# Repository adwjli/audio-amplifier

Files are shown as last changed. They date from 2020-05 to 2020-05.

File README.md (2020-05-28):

# Audio Amplifier

## Introduction
This is a Class D audio amplifier built around a TPA3122D2N amplifier from Texas Instrument. It features two stereo audio jacks that allows two sources to be connected to the amplifier at the same time (for example a music player and a laptop).

A slide switch allows selection of switch input source to feed into the amplifier. The onboard potentiometer provides volume control. Power is provided using a 16V DC 2A adapter. This audio amplifier was designed as part of a custom audio-visual setup.

The amplifier accepts an input voltage between 15V to 25V. The output power is 10W per channel. It can drive speakers with impedances between 4 and 8 Ohms.

## Gallery

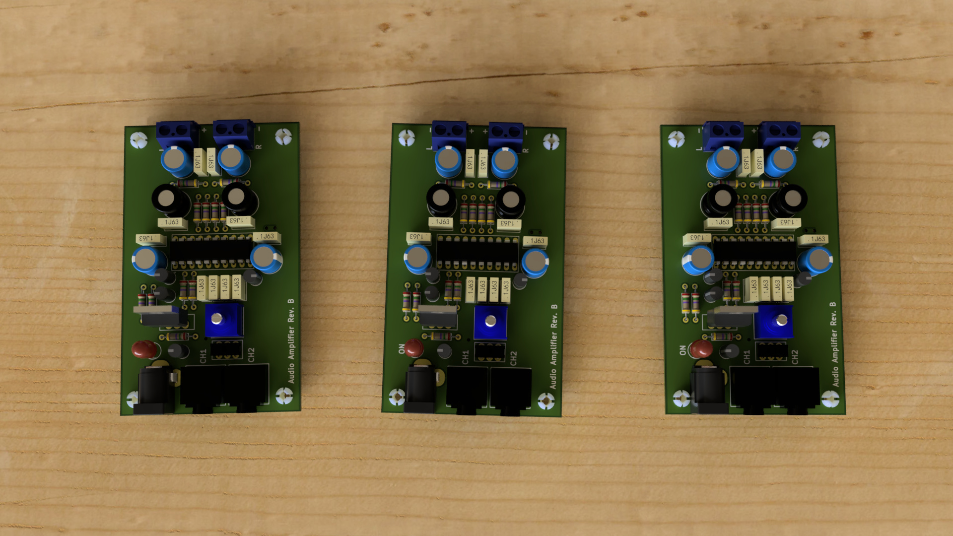
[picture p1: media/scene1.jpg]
Audio Ampifier PCBs, assembled.


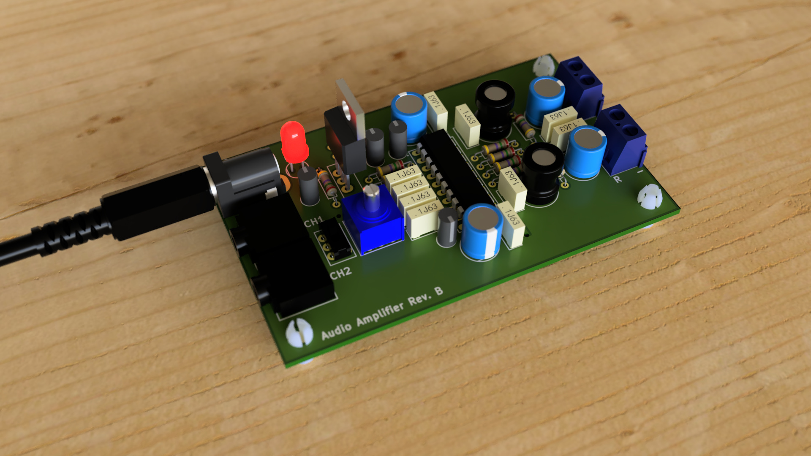
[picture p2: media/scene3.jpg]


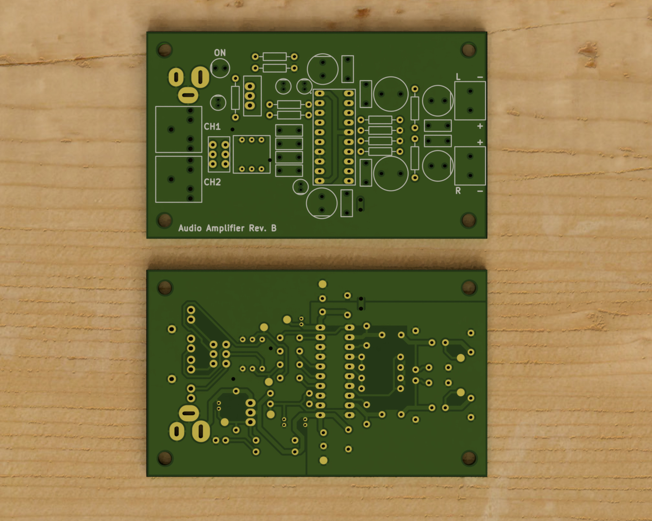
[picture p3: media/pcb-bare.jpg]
Audio Amplifier PCB bare.


## Copper Layers

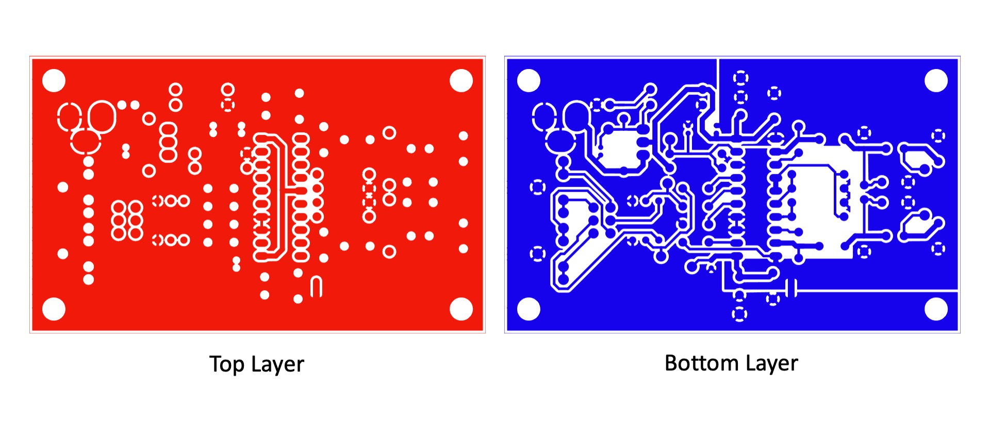
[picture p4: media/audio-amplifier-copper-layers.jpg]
Audio Amplifier powered.


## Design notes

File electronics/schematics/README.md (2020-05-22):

# Schematics

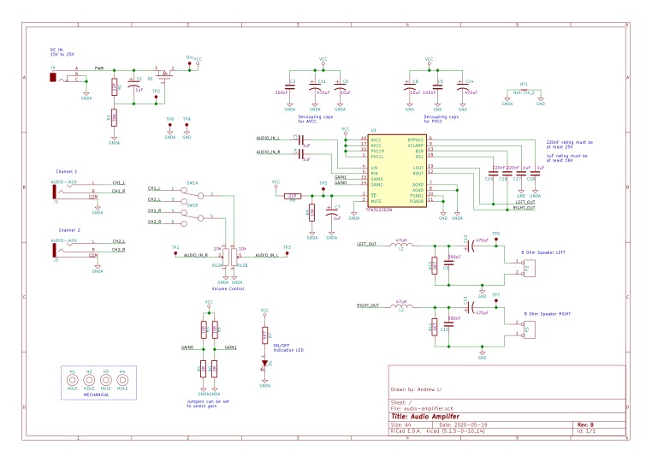
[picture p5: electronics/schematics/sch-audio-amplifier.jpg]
Schematics.


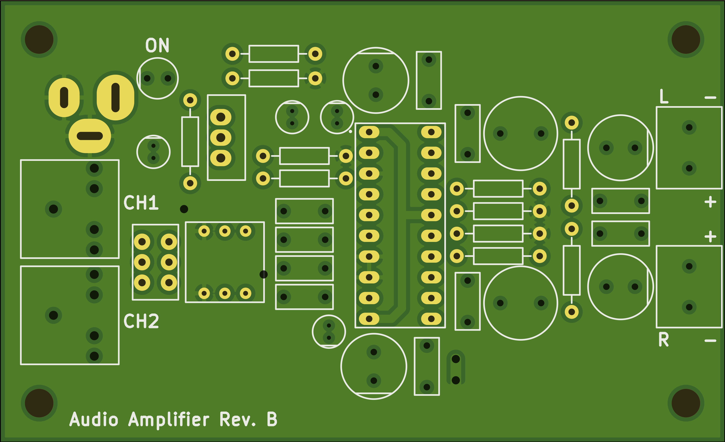
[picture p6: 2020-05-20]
electronics/raster/audio-amplifier-Front.png

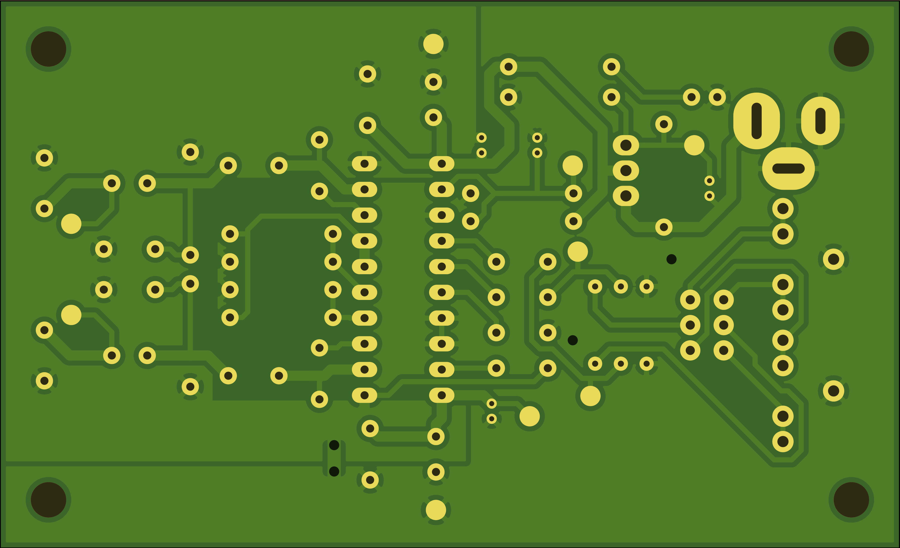
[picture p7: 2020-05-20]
electronics/raster/audio-amplifier-Back.png

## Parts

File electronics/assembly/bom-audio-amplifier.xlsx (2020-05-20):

Reference | Quantity | Value | Manufacturer | MPN | Part Description
C12 C13 C11 C14 | 4 | 470uF | ~ | ~ | Generic 470uF capacitor
C3 C4 C2 C5 C9 C10 C15 C16 C17 C18 | 10 | 1uF | ~ | ~ | Generic Through Hole Capacitor
C6 C1 C7 C8 | 4 | 10uF | ~ | ~ | Generic 10uF capacitor
D1 | 1 | ~ | ~ | ~ | Generic Through Hole LED
J1 J3 | 2 | ~ | ~ | ~ | Audio Jack
J4 | 1 | ~ | RS | 448-376 | Power socket, 2.5mm
L1 L2 | 2 | 47uH | ~ | ~ | Generic 47uH inductor
P2 P3 | 2 | ~ | ~ | ~ | Generic screw socket connector
Q1 | 1 | ~ | International Rectifier | AUIRF9Z34N | MOSFET, P-Channel, 19A, 0R1
R10 R11 R4 R6 R3 R5 R9 R8 R1 R2 R7 | 11 | 4K7 | ~ | ~ | Generic Through Hole Resistor
R12 | 1 | 10k | Bourns | 3310H-025-103L | POT 10K OHM 1/4W PLASTIC LINEAR
SW1 | 1 |  | C&K | JS202011CQN | SWITCH SLIDE DPDT 300MA 6V
U1 | 1 | ~ | Texas Instruments | TPA3122D2N | TPA3122D2N, PDIP

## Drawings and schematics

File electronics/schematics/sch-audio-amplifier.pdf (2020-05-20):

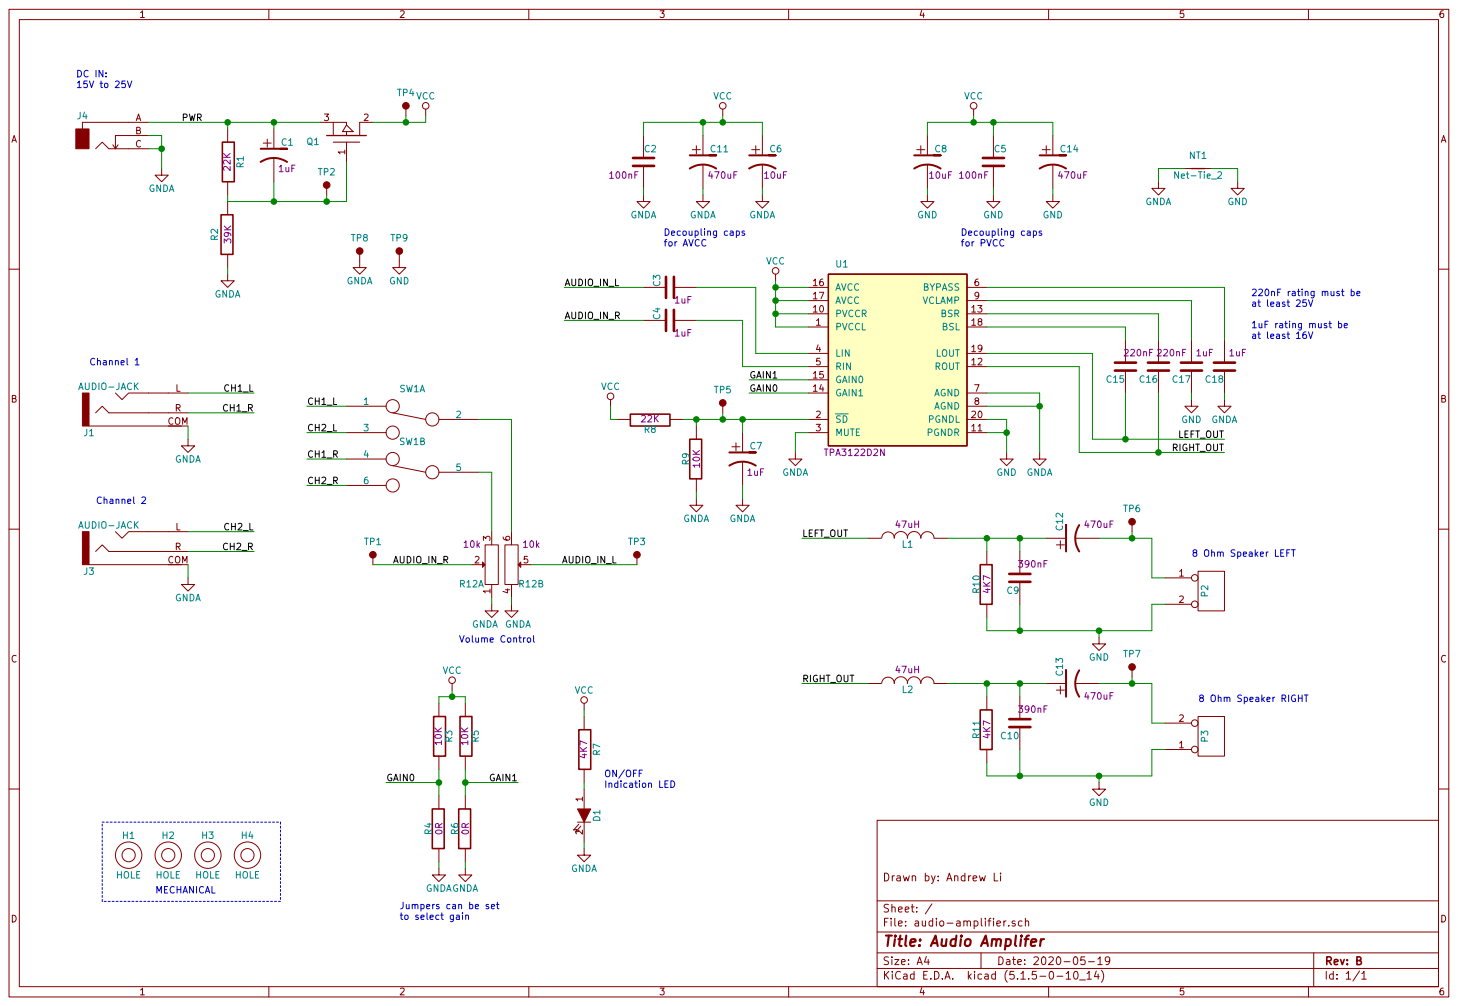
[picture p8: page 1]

8 Ohm Speaker RIGHT MECHANICAL

Jumpers can be set
to select gain

Id: 1/1 Title: Audio Amplifer

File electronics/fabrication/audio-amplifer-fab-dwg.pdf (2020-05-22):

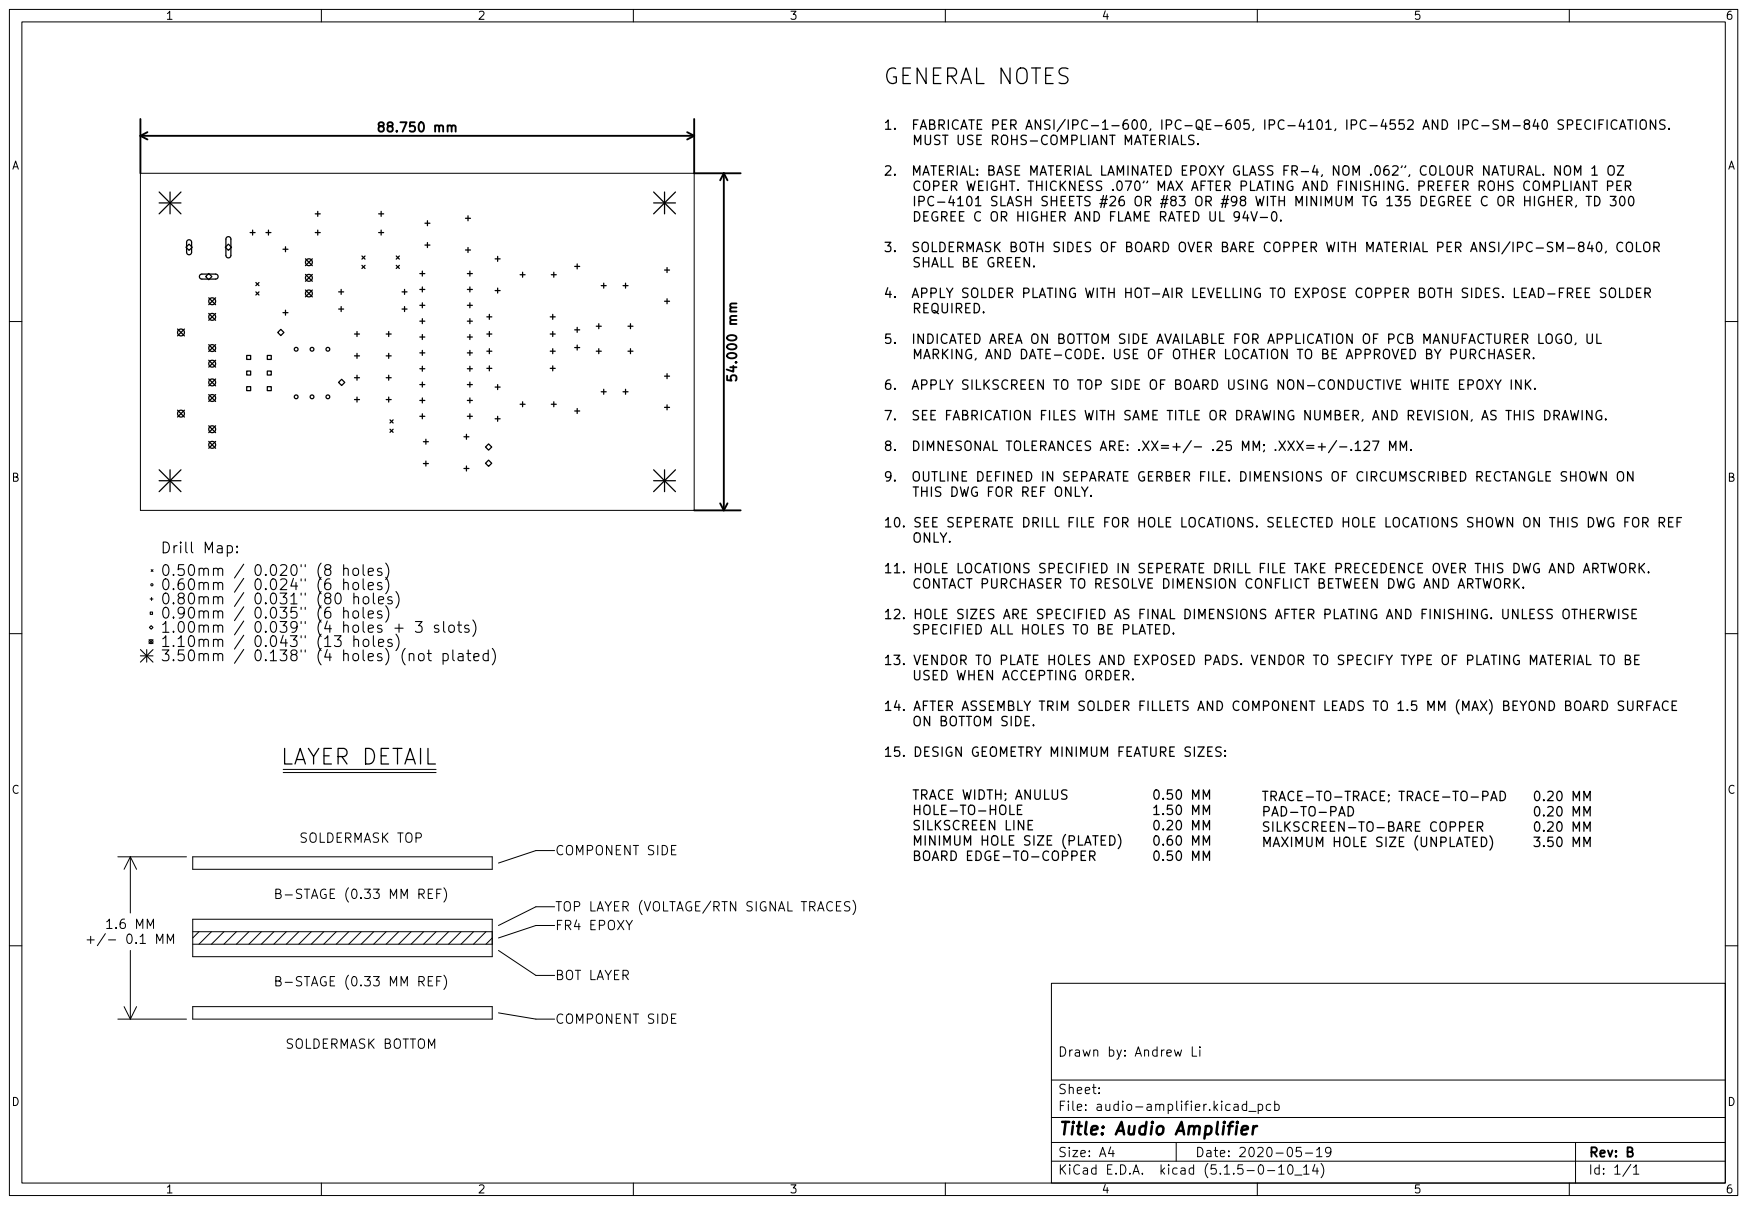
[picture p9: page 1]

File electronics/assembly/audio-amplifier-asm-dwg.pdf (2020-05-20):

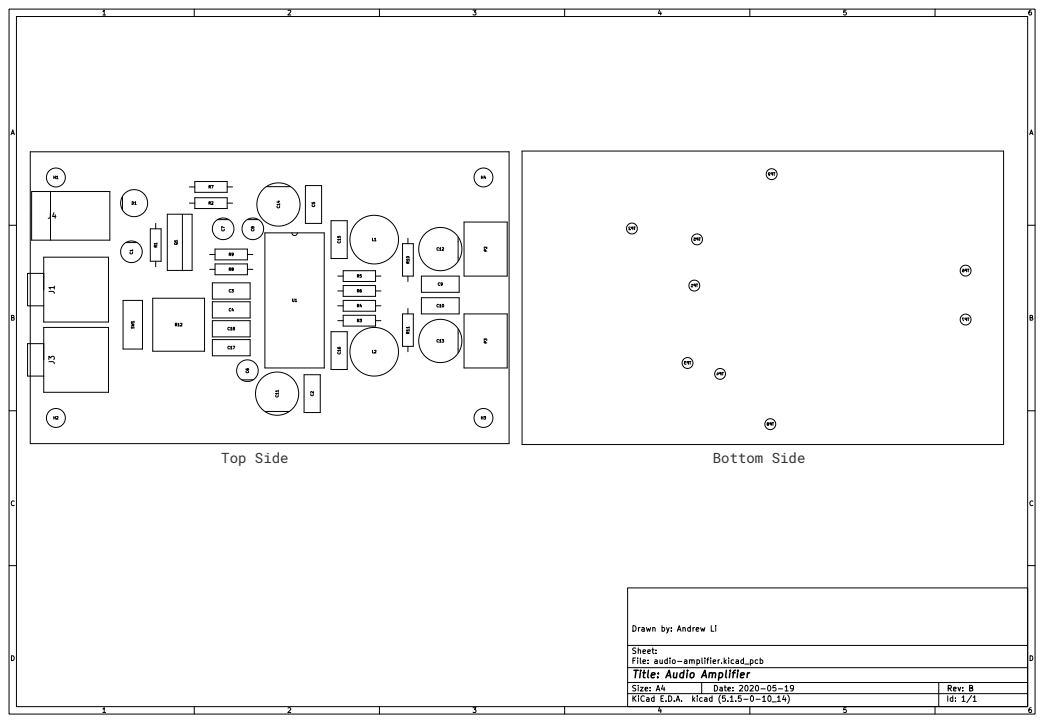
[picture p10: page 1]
Top Side; Bottom Side

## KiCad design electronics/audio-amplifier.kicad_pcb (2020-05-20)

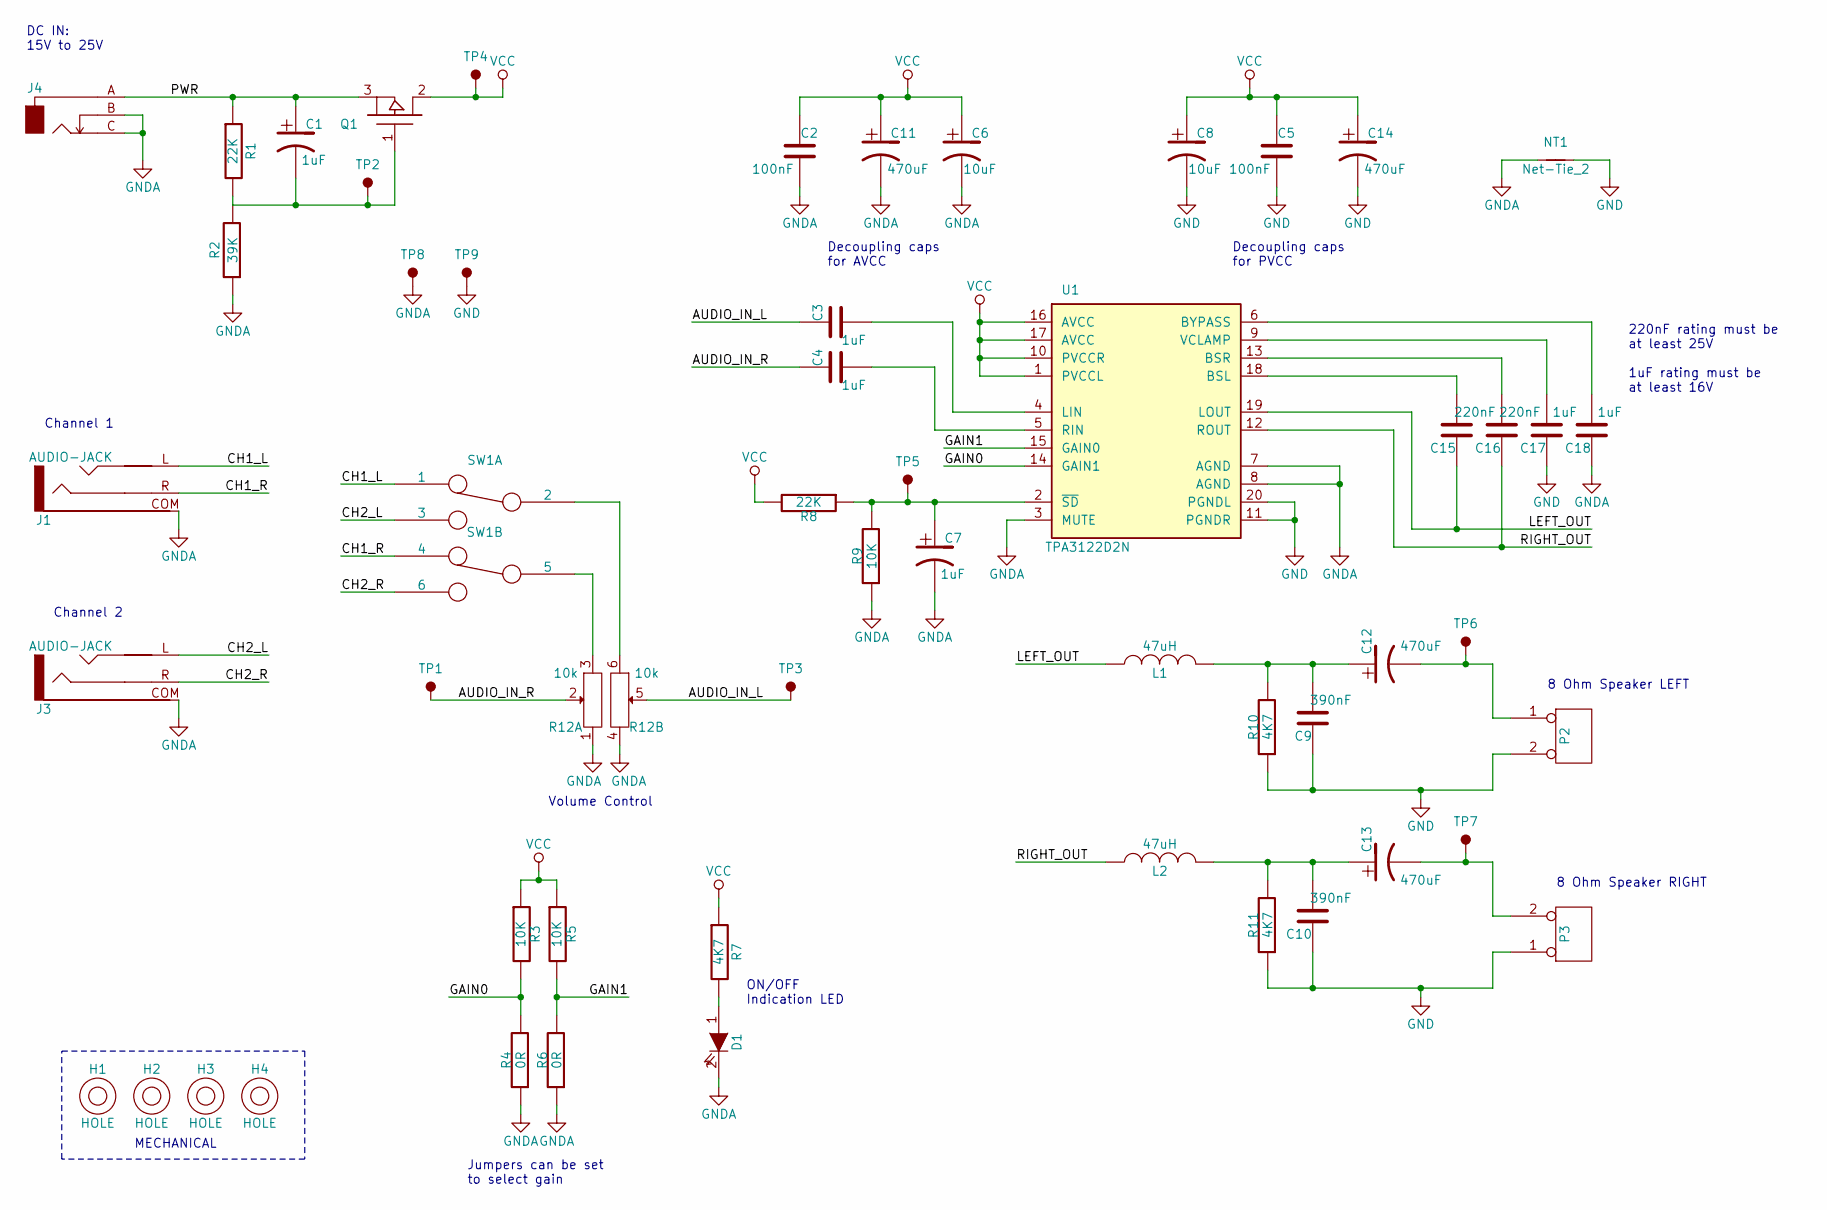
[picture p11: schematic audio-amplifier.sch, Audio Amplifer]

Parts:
C1, C6, C7, C8: CAP-POL-GENERIC; CAP-POL-GENERIC-TH-D4MM-P1.5MM
C2, C3, C4, C5, C9, C10, C15, C16, C17, C18: CAP-GENERIC; CAP-GENERIC-TH; Part Description Generic Through Hole Capacitor
C11, C12, C13, C14: CAP-POL-GENERIC; CAP-POL-GENERIC-TH-D8MM-P3.5MM
D1: LED-GENERIC-TH; Part Description Generic Through Hole LED
H1, H2, H3, H4: HOLE; HOLE_3.5MM
J1, J3: AUDIO-JACK
J4: ECS00108; Manufacturer Part Number 448-376
L1, L2: INDUCTOR-GENERIC; INDUCTOR-GENERIC-TH-D9.0MM-P5.0MM
NT1: Net-Tie_2; NetTie-2_THT_Pad1.0mm
P2, P3: HEADER-GENERIC-2WAY; HEADER-2-TH-P5.0MM
Q1: ECS00110; ECTO-220; Manufacturer Part Number AUIRF9Z34N
R1, R2, R3, R4, R5, R6, R7, R8, R9, R10, R11: RES-GENERIC; RES-GENERIC-TH; Part Description Generic Through Hole Resistor
R12: ECS00238; ECS00238F; Manufacturer Part Number 3310H-025-103L
SW1: ECS00237; ECS00237F; Manufacturer Part Number JS202011CQN
TP1, TP2, TP3, TP4, TP5, TP6, TP7, TP8, TP9: TP-2MM
U1: ECS00104; DIP-20; Manufacturer Part Number TPA3122D2N

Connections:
/AUDIO_IN_L: C3.1, R12.5, TP3.1
/AUDIO_IN_R: C4.1, R12.2, TP1.1
/CH1_L: J1.L, SW1.1
/CH1_R: J1.R, SW1.4
/CH2_L: J3.L, SW1.3
/CH2_R: J3.R, SW1.6
/GAIN0: R3.2, R4.2, U1.14 (GAIN1)
/GAIN1: R5.2, R6.2, U1.15 (GAIN0)
/LEFT_OUT: C15.1, L1.1, U1.19 (LOUT)
/PWR: C1.1, J4.A, Q1.3 (S), R1.1
/RIGHT_OUT: C16.1, L2.1, U1.12 (ROUT)
GND: C5.2, C8.2, C9.1, C10.1, C14.2, C17.1, NT1.2, P2.2 (PM), P3.1, R10.1, R11.1, TP9.1, U1.11 (PGNDR), U1.20 (PGNDL)
GNDA: C2.2, C6.2, C7.2, C11.2, C18.1, D1.2 (K), J1.COM, J3.COM, J4.B, J4.C, NT1.1, R2.1, R4.1, R6.1, R9.1, R12.1, R12.4, TP8.1, U1.3 (MUTE), U1.7 (AGND), U1.8 (AGND)
unnamed: C1.2, Q1.1 (G), R1.2, R2.2, TP2.1
unnamed: C3.2, U1.4 (LIN)
unnamed: C4.2, U1.5 (RIN)
unnamed: C7.1, R8.1, R9.2, TP5.1, U1.2 (~SD)
unnamed: C10.2, C13.1, L2.2, R11.2
unnamed: C9.2, C12.1, L1.2, R10.2
unnamed: C12.2, P2.1, TP6.1
unnamed: C13.2, P3.2 (PM), TP7.1
unnamed: C15.2, U1.18 (BSL)
unnamed: C16.2, U1.13 (BSR)
unnamed: C17.2, U1.9 (VCLAMP)
unnamed: C18.2, U1.6 (BYPASS)
unnamed: D1.1 (A), R7.2
unnamed: R12.3, SW1.5
unnamed: R12.6, SW1.2
VCC: C2.1, C5.1, C6.1, C8.1, C11.1, C14.1, Q1.2 (D), R3.1, R5.1, R7.1, R8.2, TP4.1, U1.1 (PVCCL), U1.10 (PVCCR), U1.16 (AVCC), U1.17 (AVCC)

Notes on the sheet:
ON/OFF Indication LED
Jumpers can be set to select gain
8 Ohm Speaker LEFT
8 Ohm Speaker RIGHT
220nF rating must be at least 25V 1uF rating must be at least 16V
Decoupling caps for PVCC
MECHANICAL
DC IN: 15V to 25V
Channel 1
Channel 2
Volume Control
Decoupling caps for AVCC

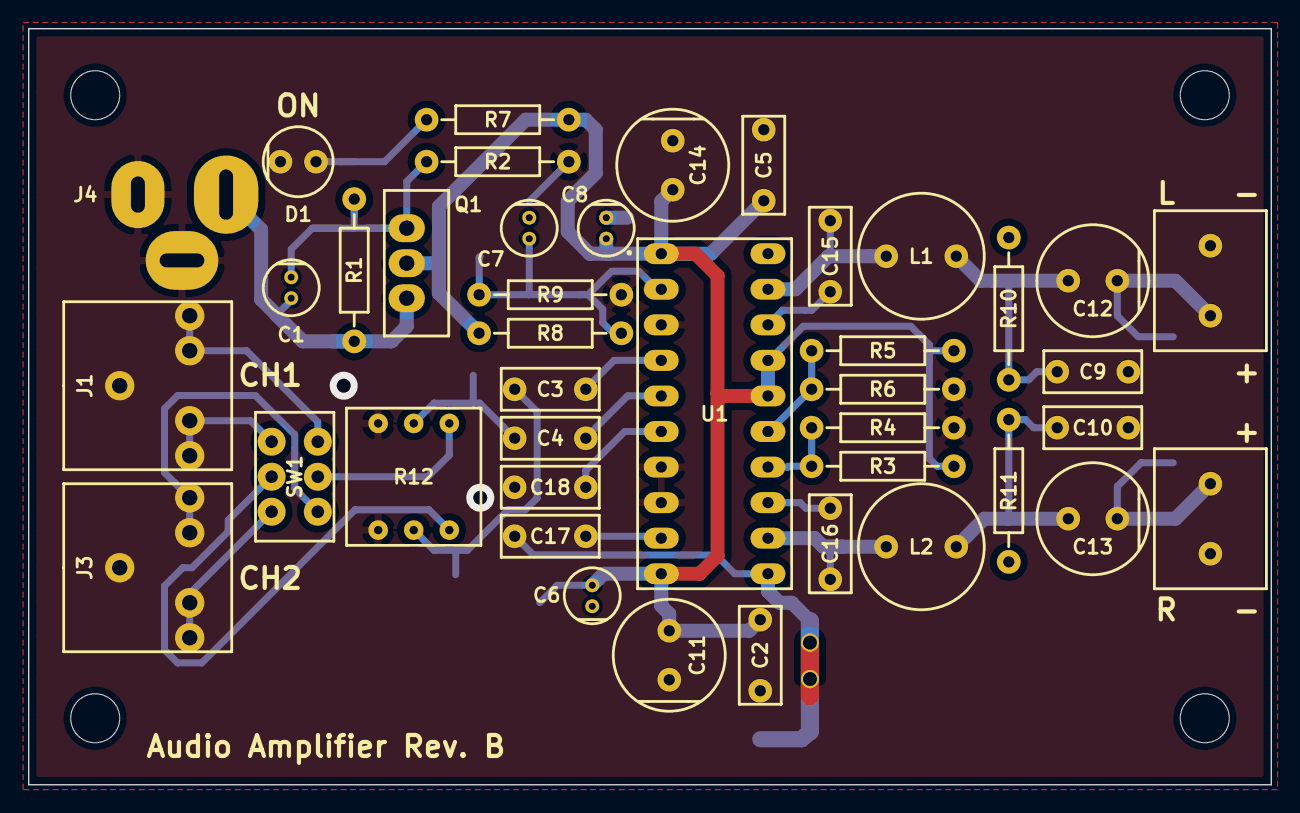
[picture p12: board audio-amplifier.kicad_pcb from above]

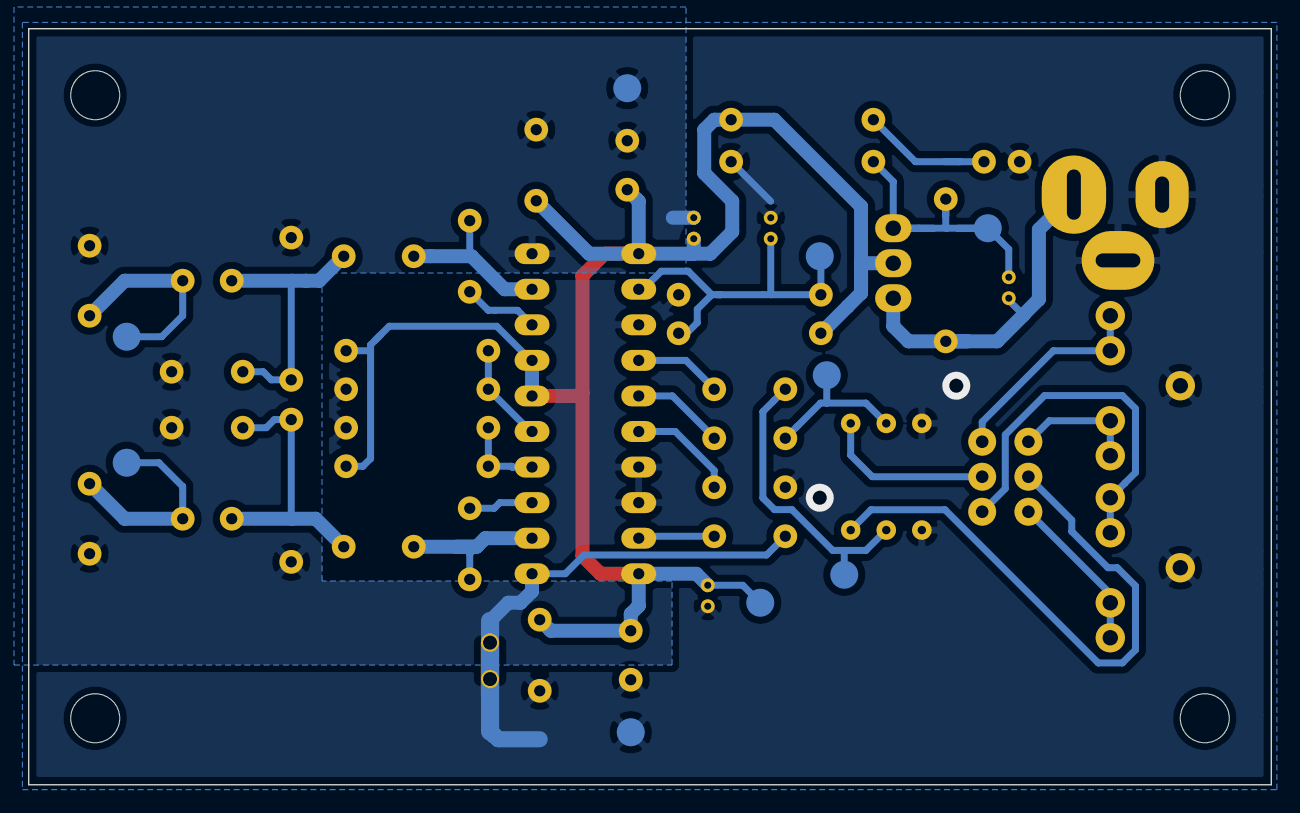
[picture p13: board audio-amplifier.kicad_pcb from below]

Board: 2 copper layers, 88.8 x 54.0 mm, 55 parts (9 on the bottom side), 29 nets.

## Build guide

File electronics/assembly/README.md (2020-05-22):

# Assembly Drawing

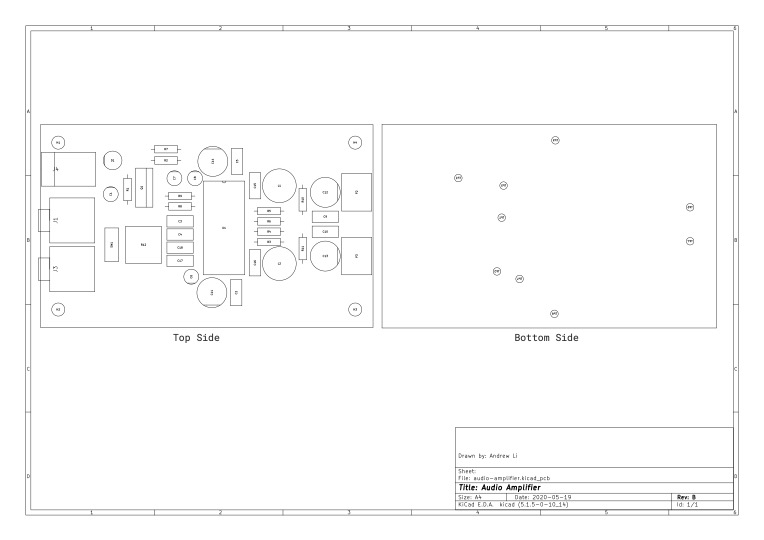
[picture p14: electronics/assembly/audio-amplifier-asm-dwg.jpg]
Assembly drawing.


| Reference 	|  Quantity 	| Value 	|  Manufacturer 	| MPN 	|  Part Description 	|
|---	|---	|---	|---	|---	|---	|
| C12 C13 C11 C14 	| 4 	| 470uF 	| ~ 	| ~ 	| Generic 470uF capacitor 	|
| C3 C4 C2 C5 C9 C10 C15 C16 C17 C18  	| 10 	| 1uF 	| ~ 	| ~ 	| Generic Through Hole Capacitor  	|
| C6 C1 C7 C8 	| 4 	| 10uF  	| ~ 	| ~ 	| Generic 10uF capacitor 	|
| D1 	| 1 	| ~ 	| ~ 	| ~ 	| Generic Through Hole LED 	|
| J1 J3 	| 2 	| ~ 	| ~ 	| ~ 	| Audio Jack 	|
| J4 	| 1 	| ~ 	| RS 	| 448-376 	| Power socket, 2.5mm 	|
| L1 L2 	| 2 	| 47uH  	| ~ 	| ~ 	| Generic 47uH inductor 	|
| P2 P3 	| 2 	| ~ 	| ~ 	| ~ 	| Generic screw socket connector  	|
| Q1 	| 1 	| ~ 	| International Rectifier 	| AUIRF9Z34N 	| MOSFET, P-Channel, 19A, 0R1 	|
| R10 R11 R4 R6 R3 R5 R9 R8 R1 R2 R7  	| 11 	| 4K7 	| ~ 	| ~ 	| Generic Through Hole Resistor 	|
| R12 	| 1 	| 10k 	| Bourns 	| 3310H-025-103L 	| POT 10K OHM 1/4W PLASTIC LINEAR 	|
| SW1 	| 1 	| 	| C&K 	| JS202011CQN 	| SWITCH SLIDE DPDT 300MA 6V 	|
| U1 	| 1 	| ~ 	| Texas Instruments 	| TPA3122D2N 	| TPA3122D2N, PDIP 	|

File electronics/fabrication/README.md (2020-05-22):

# Fabrication Drawing

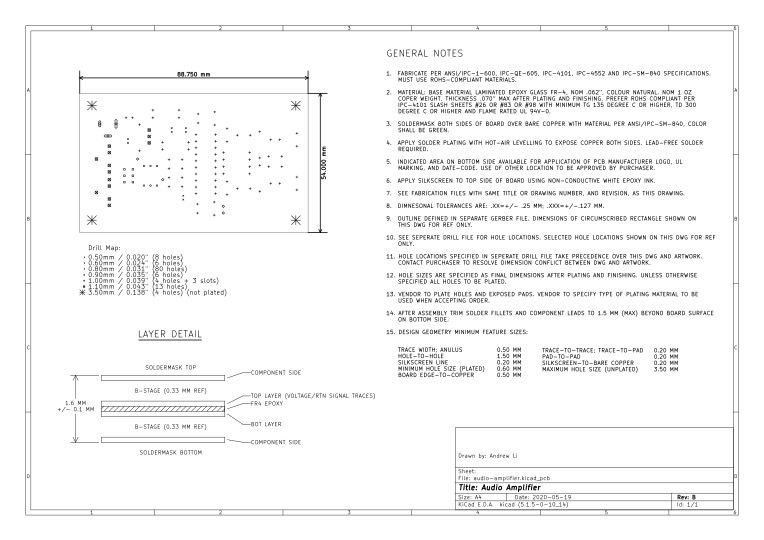
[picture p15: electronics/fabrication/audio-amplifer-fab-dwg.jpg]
Fabrication drawing.


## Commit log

2020-05-15 First commit.
    [audio-amplifier.kicad_pcb, audio-amplifier.sch]
2020-05-20 Uploading completed design files.
    [audio-amplifier-B_Cu.gbl, audio-amplifier-B_Mask.gbs, audio-amplifier-B_SilkS.gbo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]
